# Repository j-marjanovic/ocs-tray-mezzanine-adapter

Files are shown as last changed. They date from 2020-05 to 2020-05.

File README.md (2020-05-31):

# OCS Tray Mezzanine Adapter, version 1

## The adapter in action

Here we can see the adapter board connecting the PCIe (x1, over USB) to the FPGA
board, 12V power from the ATX power supply, and I2C to the Raspberry Pi.

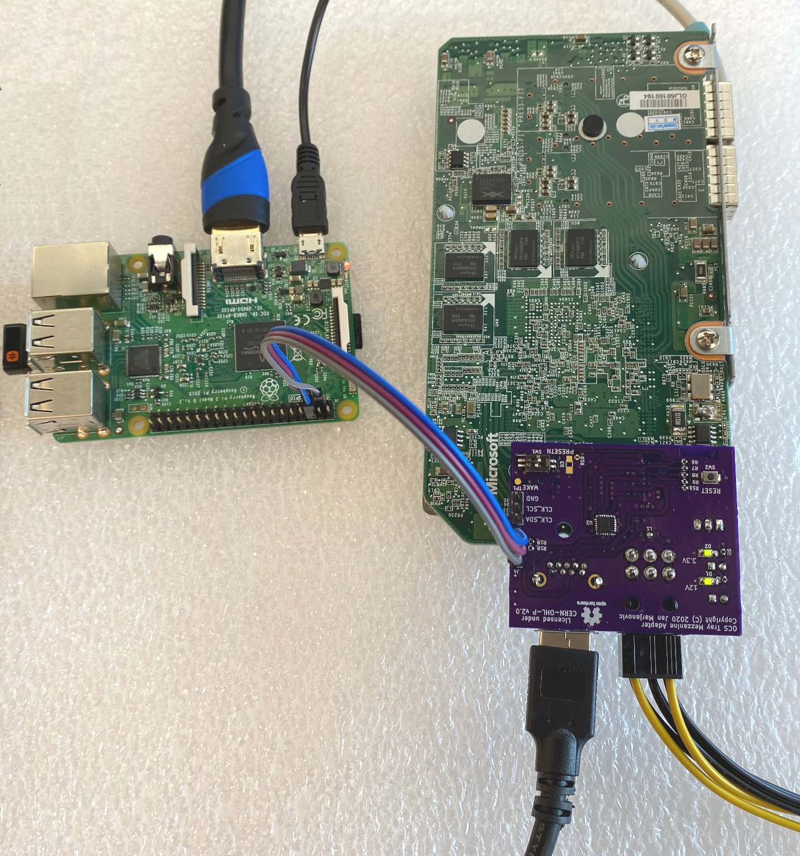
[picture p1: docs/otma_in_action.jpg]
OTMA in action


## revA

[Schematics as PDF](production/revA/ocp-tray-mezzanine-adapter-v1-revA.pdf)

Known limitations/errors:

  * Samtec connector is rotated by 180 deg - the keying pins on the sides need
    to be trimmed
  * Pin 4 on the USB should be not be connected to the board; it should either
    be trimmed before soldering or the via should be removed
  * The mounting hole is slightly misaligned

## TODO for revB

  * solder mask keep-out for PCIe lanes 7, 8 and 15
  * solder mask keep-out for layer indicators
  * move label R2 (silkscreen over pad)
  * (optional) labels for SDA, SCL and GND on MEZZ I2C connector
  * mode capacitors C1 and C5 to the other side (shorter traces)
  * pin 1 and 4 on the USB connector carry the PCIe signals, fix the connections
  * the LED for the mezzanine present signals has wrong polarity, it should be
    powered from 3V3
  * fix the orientation of the Samtec connector
  * fix the alignment of the mounting hole

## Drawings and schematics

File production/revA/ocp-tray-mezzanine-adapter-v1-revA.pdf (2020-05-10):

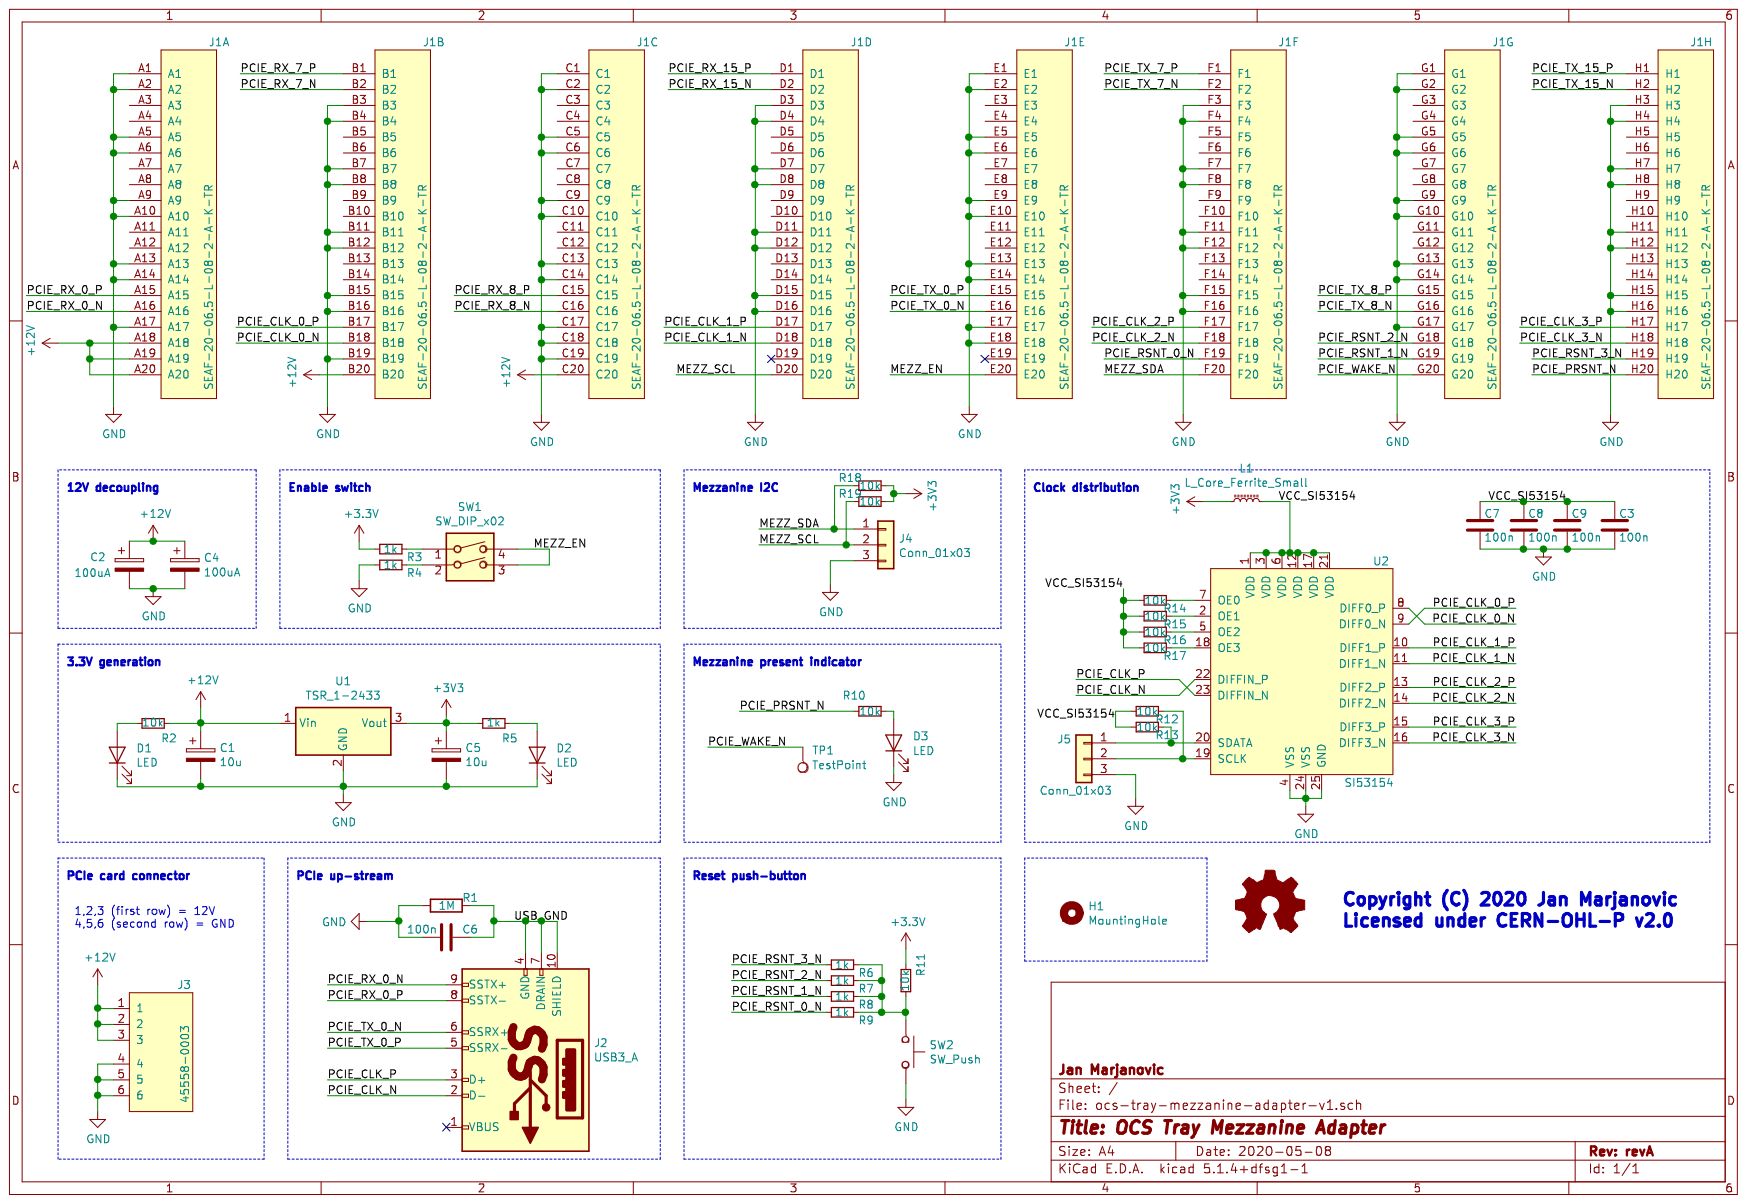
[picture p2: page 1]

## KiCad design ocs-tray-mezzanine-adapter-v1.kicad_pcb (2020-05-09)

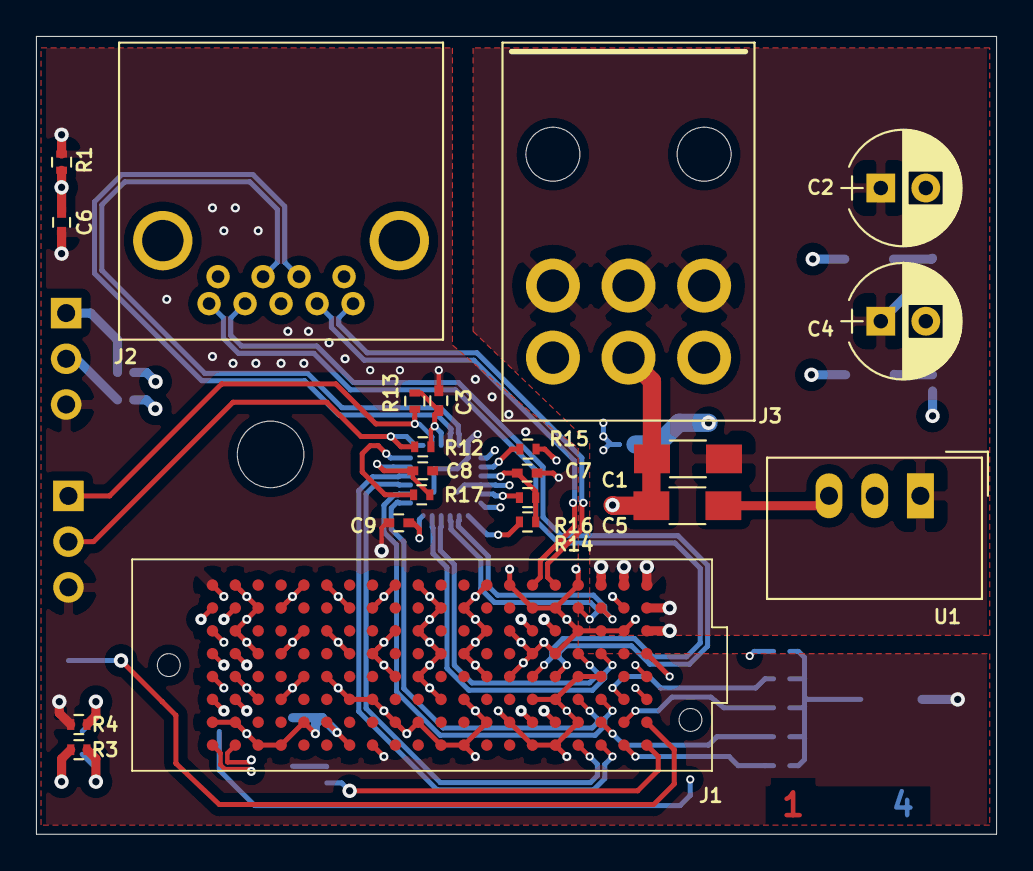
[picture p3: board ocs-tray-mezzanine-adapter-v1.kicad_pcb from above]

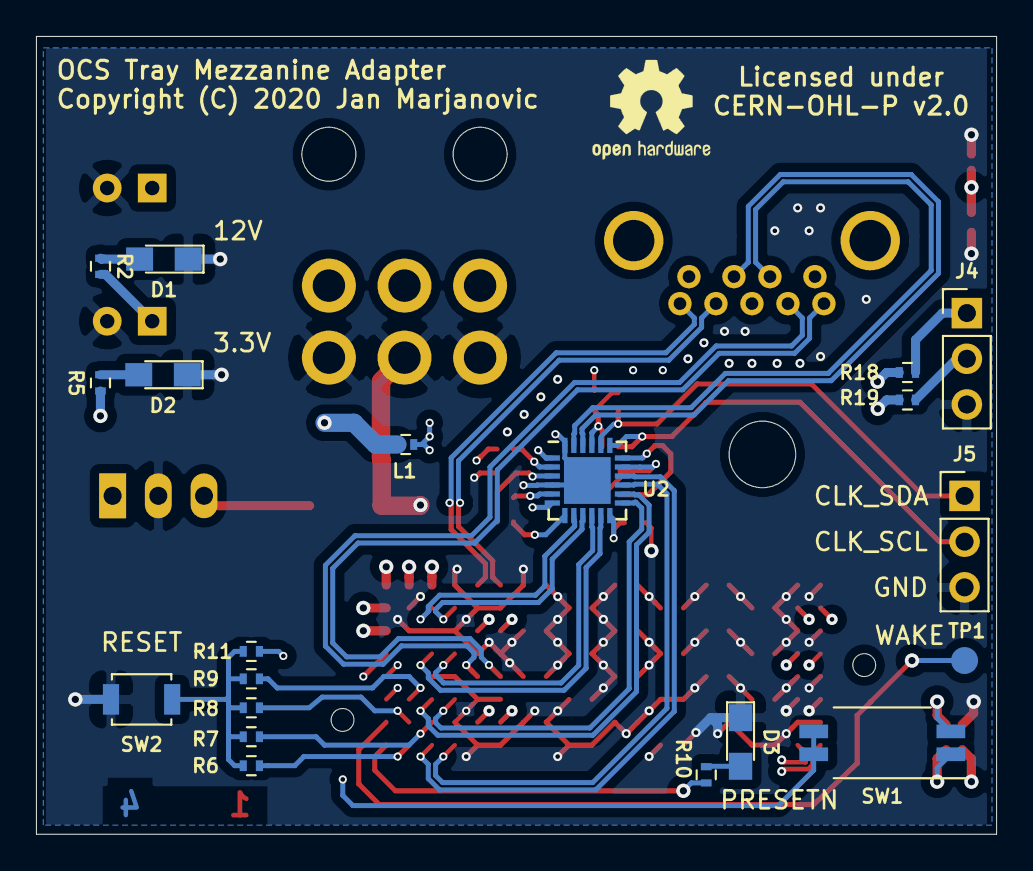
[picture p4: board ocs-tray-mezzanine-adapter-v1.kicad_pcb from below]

Board: 4 copper layers, 53.3 x 44.3 mm, 43 parts (20 on the bottom side), 40 nets.

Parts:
C1, C5: 10u; C_1206_HandSoldering
C2, C4: 100uA; CP_Radial_D6.3mm_P2.50mm
C3, C6, C7, C8, C9: 100n; C_0402
D1, D2, D3: LED; LED_0805_HandSoldering
H1: MountingHole; MountingHole_3.7mm
J1: SEAF-20-06.5-L-08-2-A-K-TR; samtec_searay
J2: USB3_A; 692121030100
J3: 45558-0003
J4, J5: Conn_01x03; Pin_Header_Straight_1x03_Pitch2.54mm
L1: L_Core_Ferrite_Small; L_0402
R1: 1M; R_0402
R2, R10, R11, R12, R13, R14, R15, R16, R17, R18, R19: 10k; R_0402
R3, R4, R5, R6, R7, R8, R9: 1k; R_0402
SW1: SW_DIP_x02; SW_DIP_x2_W7.62mm_Slide_Copal_CHS-B
SW2: SW_Push; SW_SPST_B3U-1000P
TP1: TestPoint; Measurement_Point_Round-SMD-Pad_Small
U1: TSR_1-2433; Converter_DCDC_TRACO_TSR-1_THT
U2: SI53154; QFN-24-1EP_4x4mm_Pitch0.5mm

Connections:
+3V3: C5.1, L1.1, R3.2, R5.1, R11.2, R18.1, R19.1, U1.3
+12V: C1.1, C2.1, C4.1, J1.A18, J1.A19, J1.A20, J1.B20, J1.C20, J3.1, J3.2, J3.3, R2.2, U1.1
/MEZZ_EN: J1.E20, SW1.3, SW1.4
/MEZZ_SCL: J1.D20, J4.2, R19.2
/MEZZ_SDA: J1.F20, J4.1, R18.2
/PCIE_CLK_0_N: J1.B18, U2.8
/PCIE_CLK_0_P: J1.B17, U2.9
/PCIE_CLK_1_N: J1.D18, U2.11
/PCIE_CLK_1_P: J1.D17, U2.10
/PCIE_CLK_2_N: J1.F18, U2.14
/PCIE_CLK_2_P: J1.F17, U2.13
/PCIE_CLK_3_N: J1.H18, U2.16
/PCIE_CLK_3_P: J1.H17, U2.15
/PCIE_CLK_N: J2.2, U2.22
/PCIE_CLK_P: J2.3, U2.23
/PCIE_PRSNT_N: J1.H20, R10.2
/PCIE_RSNT_0_N: J1.F19, R9.2
/PCIE_RSNT_1_N: J1.G19, R8.2
/PCIE_RSNT_2_N: J1.G18, R7.2
/PCIE_RSNT_3_N: J1.H19, R6.2
/PCIE_RX_0_N: J1.A16, J2.9
/PCIE_RX_0_P: J1.A15, J2.8
/PCIE_TX_0_N: J1.E16, J2.6
/PCIE_TX_0_P: J1.E15, J2.5
/PCIE_WAKE_N: J1.G20, TP1.1
/USB_GND: C6.1, J2.4, J2.7, J2.10, R1.1
/VCC_SI53154: C3.1, C7.1, C8.1, C9.1, L1.2, R12.2, R13.2, R14.2, R15.2, R16.2, R17.2, U2.1, U2.3, U2.6, U2.12, U2.17, U2.21
GND: C1.2, C2.2, C3.2, C4.2, C5.2, C6.2, C7.2, C8.2, C9.2, D1.1, D2.1, D3.1, J1.A1, J1.A2, J1.A5, J1.A6, J1.A9, J1.A10, J1.A13, J1.A14, J1.A17, J1.B3, J1.B4, J1.B7, J1.B8, J1.B11, J1.B12, J1.B15, J1.B16, J1.B19, J1.C1, J1.C2, J1.C5, J1.C6, J1.C9, J1.C10, J1.C13, J1.C14, J1.C17, J1.C18, J1.C19, J1.D3, J1.D4, J1.D7, J1.D8, J1.D11, J1.D12, J1.D15, J1.D16, J1.E1, J1.E2, J1.E5, J1.E6, J1.E9, J1.E10, J1.E13, J1.E14, J1.E17, J1.E18, J1.F3, J1.F4, J1.F7, J1.F8, J1.F11, J1.F12, J1.F15, J1.F16, J1.G1, J1.G2, J1.G5, J1.G6, J1.G9, J1.G10, J1.G13, J1.G14, J1.G17, J1.H3, J1.H4, J1.H7, J1.H8, J1.H11, J1.H12, J1.H15, J1.H16, J3.4, J3.5, J3.6, J4.3, J5.3, R1.2, R4.2, SW2.2, U1.2, U2.4, U2.24, U2.25
unnamed: D1.2, R2.1
unnamed: D2.2, R5.2
unnamed: D3.2, R10.1
unnamed: J5.1, R13.1, U2.20
unnamed: J5.2, R12.1, U2.19
unnamed: R3.1, SW1.1
unnamed: R4.1, SW1.2
unnamed: R6.1, R7.1, R8.1, R9.1, R11.1, SW2.1
unnamed: R14.1, U2.7
unnamed: R15.1, U2.2
unnamed: R16.1, U2.5
unnamed: R17.1, U2.18

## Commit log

2020-05-09 Final schematics, PCB almost done
    [ocs-tray-mezzanine-adapter-v1.kicad_pcb, ocs-tray-mezzanine-adapter-v1.sch]
2020-05-09 Revision A done
    [ocs-tray-mezzanine-adapter-v1.kicad_pcb, ocs-tray-mezzanine-adapter-v1.sch]
2020-05-10 Add schematics in PDF format
2020-05-31 Add notes from the bringup of revA board

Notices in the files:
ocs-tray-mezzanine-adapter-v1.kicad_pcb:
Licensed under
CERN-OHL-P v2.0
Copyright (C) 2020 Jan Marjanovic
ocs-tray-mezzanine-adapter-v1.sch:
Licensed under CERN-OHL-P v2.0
